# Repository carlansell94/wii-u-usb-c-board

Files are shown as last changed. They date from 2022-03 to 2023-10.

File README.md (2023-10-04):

A small board designed to replace the proprietary Wii U dock charging port with a USB type C port.

Features:
* Includes pads for 5.1k&#937; resistors, to allow the use of 'smart' chargers.
* Pads on the + output allow the addition of a switch - bridge these pads with a 0&#937; resistor if you're not using one.
* Board is a near drop-in replacement for the original - only a small amount of sanding inside the dock is required.
* No alteration to the outside of the dock is necessary (unless you add a switch).

A switchless version is also available, which removes the need to bridge the switch pads should you choose not to use one.

Included in this repository are the KiCAD files for this design. If you're only interested in having the board manufactured, gerbers are available under 'releases'.

Parts List:
* 1x 16 pin USB type C port
* 1x 0603 0&#937; resistor/1x 2 pin switch
* 2x 0603 5.1k&#937; resistors (optional)

A tri-wing screwdriver is required, to remove the dock base.

When having the board manufactured, ensure they offer a 0.8mm board thickness - I used OSH Park for mine.

For more information, take a look at [my blog post](https://qubitsandbytes.co.uk/post/convert-a-wii-u-dock-to-usb-c).

## Images
KiCAD render:

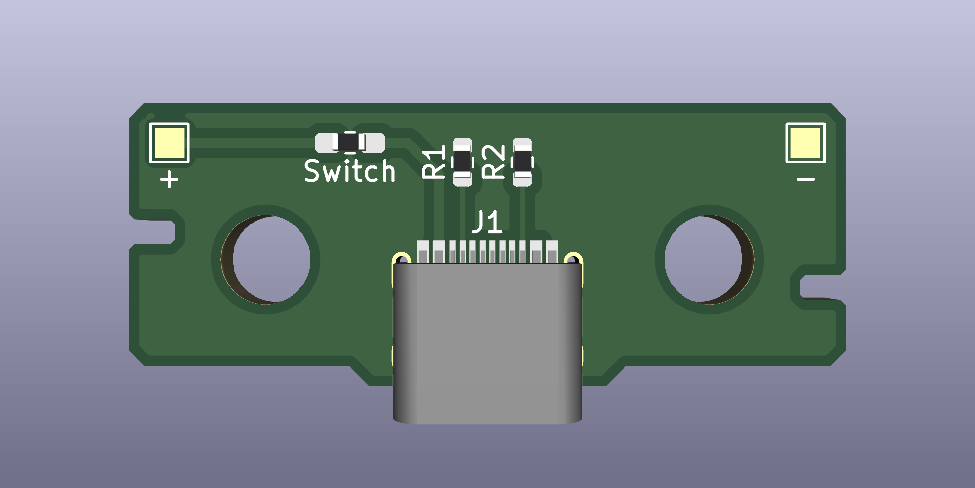
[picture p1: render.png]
KiCAD render KiCAD render of the board


Dock with added switch:

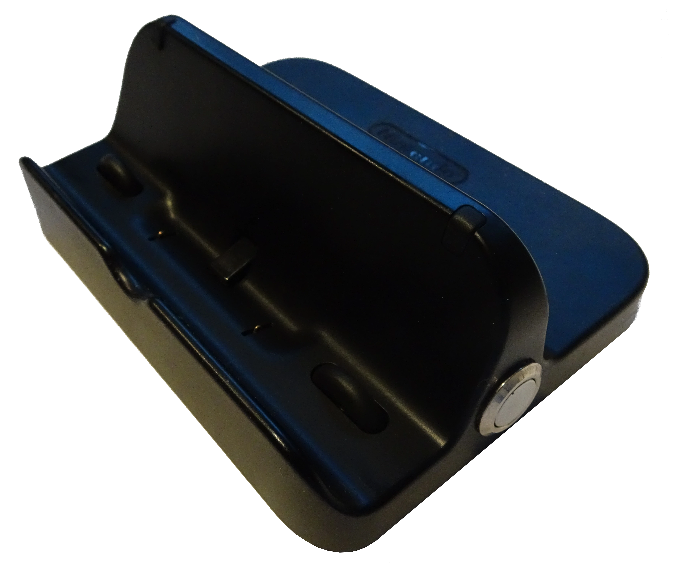
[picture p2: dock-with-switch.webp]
Dock with switch Dock with added switch


## KiCAD
The files in this project were created using KiCAD 6, which introduced a new file format not compatible with older versions. Ensure you are using KiCAD 6 if you wish to open the files.

In addition, the USB Type C port pictured in the 3D render can be found [over here](https://github.com/ai03-2725/Type-C.pretty) - the file you're looking for is 'HRO TYPE-C-31-M-12.step'. It's not required, unless you want to see the part populated using the 3D viewer.

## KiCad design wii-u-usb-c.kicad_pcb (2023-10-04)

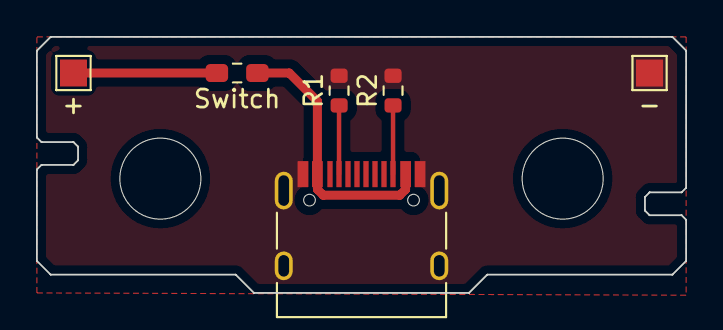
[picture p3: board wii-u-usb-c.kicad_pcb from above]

Board: 2 copper layers, 36.1 x 14.2 mm, 6 parts (0 on the bottom side), 5 nets.

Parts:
+: +; TestPoint_Pad_1.5x1.5mm
-: -; TestPoint_Pad_1.5x1.5mm
J1: USB_C_Receptacle; USB_C_Receptacle_HRO_TYPE-C-31-M-12
R1, R2: 5.1k; R_0603_1608Metric
Switch: 0; R_0603_1608Metric

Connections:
GND: -.1, J1.A1 (GND), J1.A12 (GND), J1.B1 (GND), J1.B12 (GND), J1.S1 (SHIELD), R1.2, R2.2
unnamed: J1.A4 (VBUS), J1.A9 (VBUS), J1.B4 (VBUS), J1.B9 (VBUS), Switch.1
unnamed: J1.A5 (CC1), R1.1
unnamed: J1.B5 (CC2), R2.1
unnamed: +.1, Switch.2

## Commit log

2023-10-04 feat: Add switchless version
    [wii-u-usb-c-no-switch.kicad_pcb, wii-u-usb-c-no-switch.kicad_sch]
2023-10-04 feat: Update to KiCAD v7 file format
    [wii-u-usb-c.kicad_pcb, wii-u-usb-c.kicad_sch]
